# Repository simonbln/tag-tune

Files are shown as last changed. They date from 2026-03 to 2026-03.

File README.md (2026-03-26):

# tag-tune
An open-source, USB-powered audio player that brings physical objects to life.

## Table of Contents
1. [Components](#components)
2. [Wiring Diagram](#wiring-diagram)
3. [Firmware Details](#firmware-details)
4. [DFPlayer Mini & SD Card Setup](#dfplayer-mini--sd-card-setup)
5. [LED Status Indicators](#led-status-indicators)
6. [How to Use](#how-to-use)
7. [How to Build](#how-to-build)
    - [Breadboard Prototyping](#breadboard-prototyping)
    - [Firmware Setup](#firmware-setup)
    - [Important: USB Power Handling](#important-usb-power-handling)
    - [Build Prototype](#build-prototype)
8. [Support Me](#support-me)
9. [Third-Party Code and License](#third-party-code-and-license)

## Components
- RP2040 (Zero)
- DFPlayer Mini
- RC522 NFC reader
- USB Connector
- WS2812 (NeoPixel LED)
- 2 Speaker 3 Ohm 
- Micro SD Card
- Perfboard (5x7cm)
- Connectors / Cables
- Enclosure / Box

## Wiring Diagram
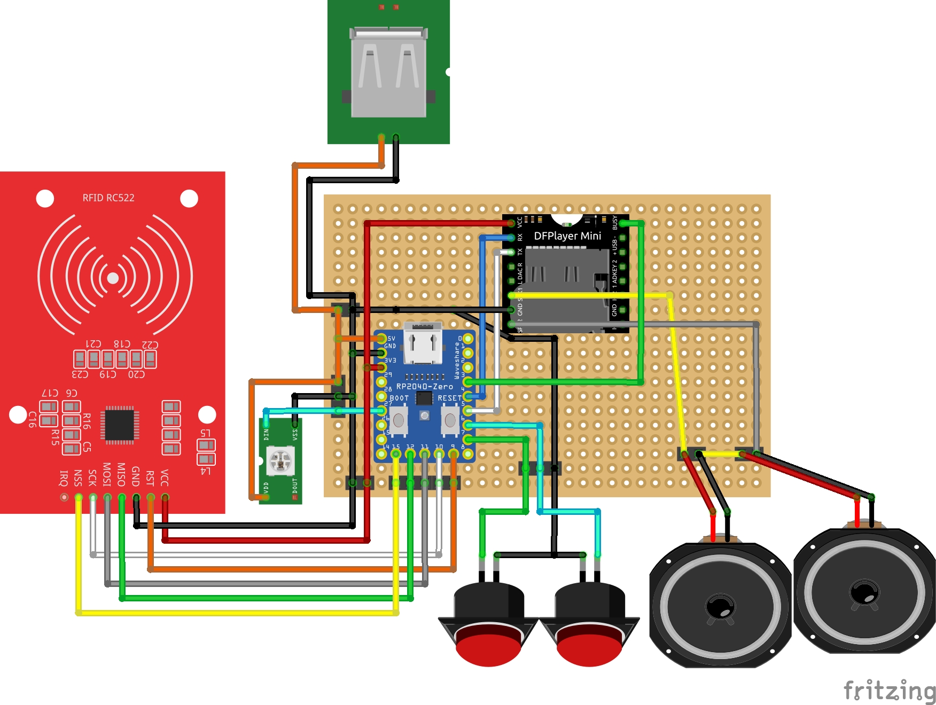
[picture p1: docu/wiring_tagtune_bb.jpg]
Wiring Diagram

Figure 1: Wiring diagram on the perfboard

## Firmware Details
The firmware is written in **MicroPython** and utilizes a modified version of the [penguintutor/dfplayermini-pico](https://github.com/penguintutor/dfplayermini-pico) library.

## DFPlayer Mini & SD Card Setup
The DFPlayer Mini requires the SD card to be formatted to **FAT16 or FAT32**.

### SD Card Structure
The module requires a specific file naming convention to function reliably:
- **Folder naming:** Use a folder named `01` in the root directory.
- **File naming:** Files should be prefixed with a three-digit number (e.g., `001.mp3`).

## LED Status Indicators
The WS2812 LED (internal on PIN 16 and (optional) extenal on PIN 28) provides visual feedback on the system's state:

- **White:** System is initializing.
- **Green:** Ready and waiting for NFC tag.
- **Blue:** Valid tag and playing
- **Cyan:**  Finished playing on tag
- **Red:**: Error: No SD card or invalid tag

## How to use

Copy music or audio stories onto an SD card. Write tags as plain text on NFC tags — you can use your smartphone for that. On the tag, write the numbers of the files you want to play, separated by commas, for example: 1,2,5 will play files 1, 2, and 5 in that order. You can also use ranges with a minus sign, like 12-20 (plays files 12 through 20), or just a single file like 33. 

Unfortunately, I can only read about 15 bytes from Ultralight NFC tags, so the list can't be too long — in that case you can use the range format instead, for example 102-139. 

If you remove the same tag and hold it up again later, playback resumes from where it stopped. If you hold up a different tag, playback starts from the beginning. You can also just take the tag away to pause playback. Use the buttons to skip to the next or previous track with a short press, and adjust the volume with a long press. 

You can glue the tags onto figures or other objects later. Have fun with your music box :)

## How to build

### Breadboard Prototyping
For initial testing, it is recommended to build the circuit on a breadboard first as shown in the wiring diagram.

### Firmware Setup
1. Install **Thonny** IDE on your computer.
2. Flash the **MicroPython firmware** to the RP2040.  
   > **Firmware download:** [MicroPython for RP2040](https://micropython.org/download/rp2-pico/)
3. Copy all files from the `firmware` folder to the RP2040.

### Important: USB Power Handling
- **Do not** connect an external USB power source to the additional USB port while the RP2040 is connected to your computer via USB.
- Once the RP2040 is disconnected from the computer, the external USB port can be used to power all components. But for testing purpose you can use the USB Port of the RP2040.
- The external USB port will later be integrated into the enclosure.

### Build prototype
Solder the components and wires onto the perfboard as shown in Figure 1. Once the assembly is complete, perform an initial functional test before mounting the board into the enclosure.

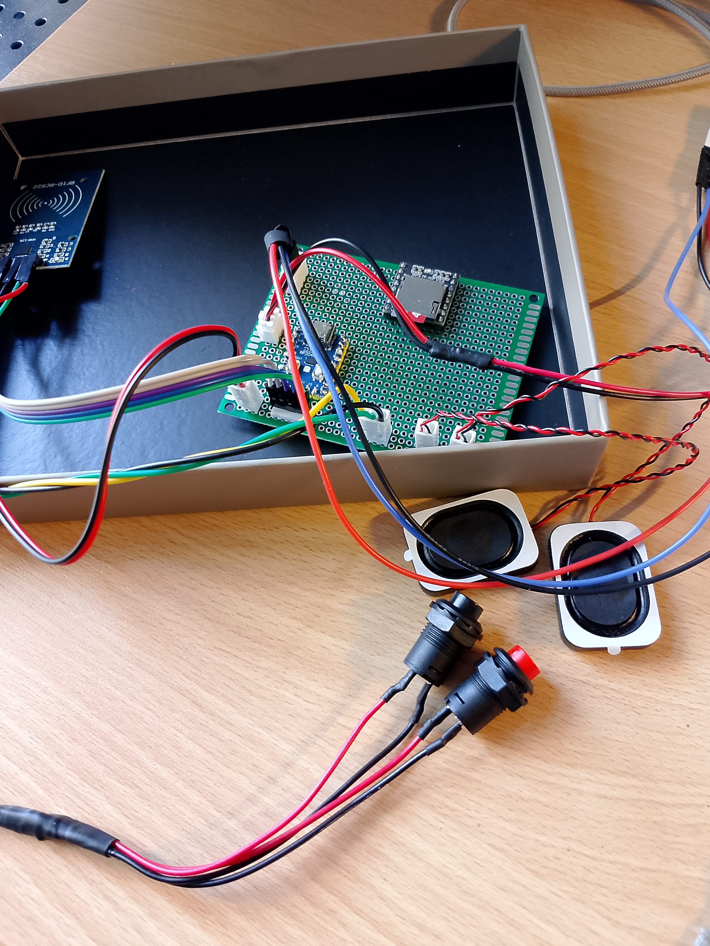
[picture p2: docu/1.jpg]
Soldering

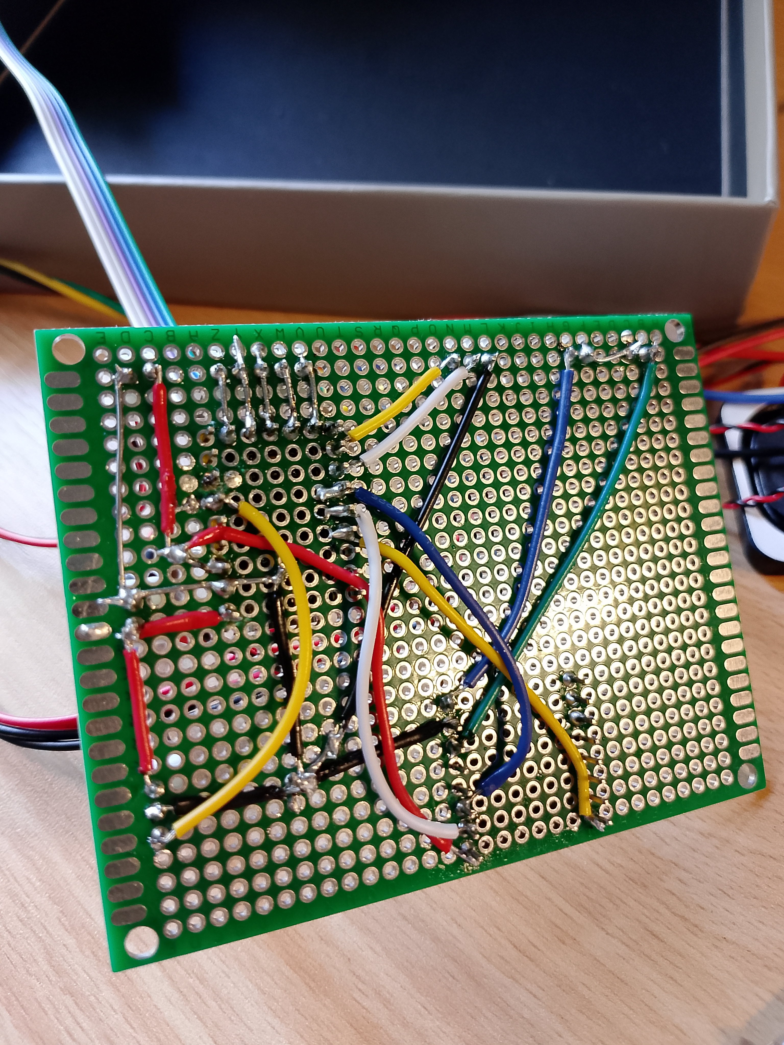
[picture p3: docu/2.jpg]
First Test


Drill the necessary holes for the cable glands and connectors, then insert them and secure with hot glue if necessary. The status LED was also routed through the lid for better visibility.

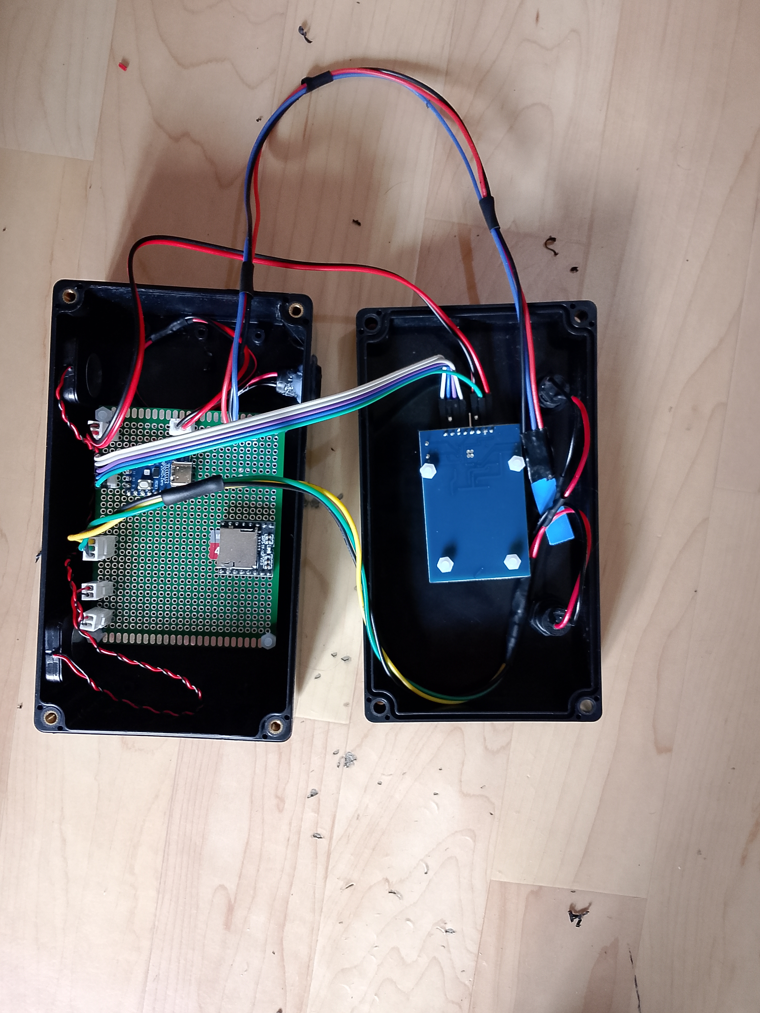
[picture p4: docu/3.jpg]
Progress

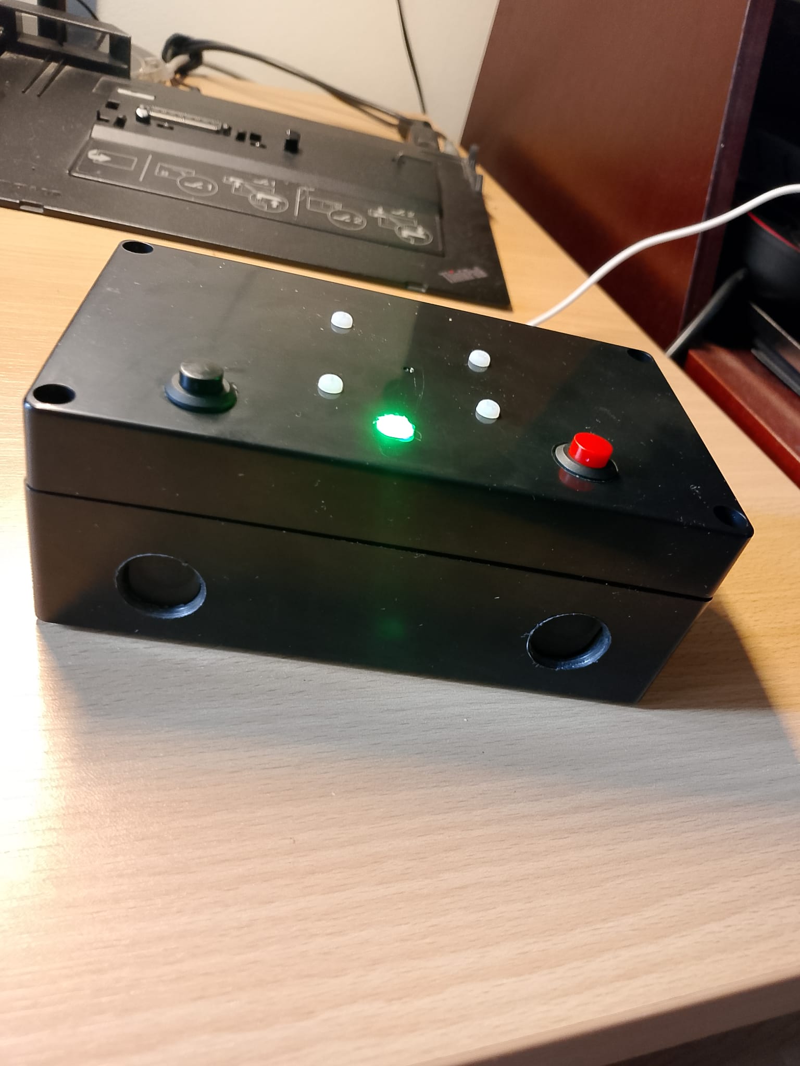
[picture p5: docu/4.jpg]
Finished


## Support me
If you find this project helpful and would like to support my work, I would be very grateful for a contribution via GitHub Sponsors or in Bitcoin (BTC) / Litecoin (LTC). Every bit of support helps me to keep creating and sharing new projects. Thank you!

### LTC:
ltc1qx2yf4cndqr2zf3vfd7l2ywm5hylvhm0a8jrxry

LTC QR Code

### BTC: 
bc1q5yga8eluxk7cn4pc7k36lwee06mwt5gtre8nrm

BTC QR Code

### Bitcoin Cash
bitcoincash:qp4gapsmpt75nh7clp64dhae2myhl9h8tg2f77w652

Bitcoin_Cash QR Code

## Third-Party Code and License

This project contains modified code from the [penguintutor/dfplayermini-pico](https://github.com/penguintutor/dfplayermini-pico) repository.

*   **Original Author:** [@PenguinTutor](https://www.penguintutor.com)
*   **Original Repository License:** **GNU General Public License v3.0** (GPL-3.0) – see full text in the original repository's `LICENSE` file.
*   **Modifications by:** ([@simonbln](https://github.com/simonbln))
*   **Date of modifications:** March 2026
*   **Nature of modifications:**
    1.  Updated `command.to_bytes(1)` to `command.to_bytes(1, 'big')` for compatibility with newer Python versions.
    2.  Fixed the return value parsing for the reset command to correctly handle the module's response.

This modified version is distributed under the same license terms (GPL-3.0). The complete license text is included in this repository as `LICENSE`.

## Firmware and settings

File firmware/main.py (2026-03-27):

from machine import Pin, UART, lightsleep, SPI
from mfrc522 import MFRC522
import utime
import time
import neopixel
import time
import random
from dfplayermini import DFPlayerMini

class NDEFDataManager:
    def __init__(self, reader, max_files):
        self.reader = reader
        self.max_files = max_files
        self.last_text = None
        self.values = []
        self.current_index = 0
        self.has_error = False
        self._is_resuming = False # Internal state for shall_resume()

    def check(self):
        """Reads the tag and manages the resume/state logic."""
        raw_text = self._read_from_tag()
        self._is_resuming = False # Reset resume state by default

        # Case 1: Tag was removed (raw_text is None)
        if raw_text is None:
            if self.last_text is not None:
                # Tag lost: clear active state but keep index/saved_text for potential resume
                self.last_text = None
                print("check: tag gone")
                return True # Status change: tag gone
            return False

        # Case 2: A tag is present
        # Check against hidden buffer to see if it's the SAME tag as before
        if hasattr(self, '_saved_text') and raw_text == self._saved_text:
            # Same tag content detected
            if self.last_text is None: # It was away, now it's back
                self.last_text = raw_text
                # If there are elements left, enable resume; otherwise restart from 0
                if self.current_index < len(self.values) and self.current_index >= 0:
                    self._is_resuming = True
                else:
                    self.current_index = 0
                    print(f"check: tag is back: {raw_text}")
                return True
            return False

        # Case 3: A completely new tag (or content changed)
        self.last_text = raw_text
        self._saved_text = raw_text # Persistent memory for resume check
        self.current_index = 0
        self._parse_values(raw_text)
        print(f"check: tag is new: {raw_text}")
        return True

    def shall_resume(self):
        """Returns True if the same tag was reapplied and has pending values."""
        return self._is_resuming

    def has_valid_tag(self):
        """Returns True if a tag is currently being detected."""
        return self.last_text is not None
    
    def get_first_value(self):
        if self.current_index < (len(self.values)) and self.current_index >= 0:
            val = self.values[self.current_index]
            print(f"get_first_value: {val}")
            if val <= self.max_files:
                print(f"get_first_value: {val}: OK")
                return val
        print("get_first_value: is not valid, get next")
        return self.get_next_value()

    def get_next_value(self):
        while self.current_index < (len(self.values)-1):
            self.current_index += 1
            val = self.values[self.current_index]
            print(f"get_next_val: {val}")
            if val <= self.max_files:
                print(f"get_next_val: {val}: OK")
                return val
        print(f"get_next_val: nothing found")
        self.current_index = len(self.values)
        return None
    
    def get_prev_value(self):
        while self.current_index > 0:
            self.current_index -= 1
            val = self.values[self.current_index]
            print(f"get_prev_value: {val}")
            if val <= self.max_files:
                print(f"get_prev_value: {val}: OK")
                return val
        print(f"get_prev_value: nothing found")
        self.current_index = -1
        return None
 

    def _parse_values(self, text):
        """Parses comma-separated string into an integer list.
           Supports ranges like '4-50' which expand to 4,5,6,...,50.
        """
        self.values = []
        self.current_index = 0
        self.has_error = False
        try:
            parts = text.strip().split(',')
            for p in parts:
                cleaned = p.strip()
                if not cleaned:
                    continue
                try:
                    # Einzelne ganze Zahl
                    self.values.append(int(cleaned))
                except ValueError:
                    # Keine einzelne Zahl → möglicher Bereich
                    if '-' in cleaned:
                        range_parts = cleaned.split('-')
                        if len(range_parts) == 2:
                            start_str, end_str = range_parts
                            start = int(start_str.strip())
                            end = int(end_str.strip())
                            if start <= end:
                                self.values.extend(range(start, end+1))
                            else:
                                raise ValueError("Invalid range: start > end")
                        else:
                            raise ValueError("Invalid range format: more than one dash")
                    else:
                        raise ValueError("Invalid integer or range")
        except ValueError:
            self.has_error = True
            self.values = []

    def _read_from_tag(self):
        """Hybrid read logic for Ultralight and Classic tags."""
        all_raw_data = bytearray()
        
        self.reader.init()
        (stat, _) = self.reader.request(self.reader.REQIDL)
        if stat != self.reader.OK: return None
        (stat, uid) = self.reader.SelectTagSN()
        if stat != self.reader.OK: return None

        # Try Ultralight first (Pages 4-15)
        for page in range(4, 16):
            s, d = self.reader.read(page)
            if s == self.reader.OK and d:
                all_raw_data.extend(bytes(d))
            else: break

        # Try Classic if Ultralight yielded no NDEF data
        if len(all_raw_data) < 7:
            self.reader.stop_crypto1() # Clean up state
            self.reader.init()
            self.reader.request(self.reader.REQIDL)
            self.reader.SelectTagSN()
            nextKey = [0xD3, 0xF7, 0xD3, 0xF7, 0xD3, 0xF7]
            for b in [0, 1, 2]:
                res = self.reader.readSectorBlock(uid, 1, b, nextKey, None)
                s, d = res if isinstance(res, tuple) else (self.reader.OK, res)
                if s == self.reader.OK and d:
                    all_raw_data.extend(bytes(d))
            self.reader.stop_crypto1()

        # NDEF Text Record Parser
        i = 0
        while i < len(all_raw_data) - 4:
            if all_raw_data[i] == 0x03: # NDEF Start
                msg_len = all_raw_data[i+1]
                try:
                    for j in range(i + 2, i + 8):
                        if all_raw_data[j] == 0x54: # 'T' identifier
                            p_len = all_raw_data[j-1]
                            l_len = all_raw_data[j+1] & 0x3F
                            start = j + 2 + l_len
                            end = j + 1 + p_len
                            return all_raw_data[start:end].decode('utf-8')
                except: pass
                i += 2 + msg_len
            elif all_raw_data[i] == 0xFE: break # NDEF End
            else: i += 1
        return None



# --- Configuration ---
BTN_NEXT_PIN = 6
BTN_PREV_PIN = 7
DEBOUNCE_MS = 50 
LONG_PRESS_MS = 1000
VOL_STEP_MS = 500

BUSY_PIN = 3

LED1_PIN = 16
LED2_PIN = 27

# --- Global States ---
# We store (timestamp, is_pressed)
btn_states = {
    BTN_NEXT_PIN: {"start_time": 0, "active": False, "long_done": False},
    BTN_PREV_PIN: {"start_time": 0, "active": False, "long_done": False}
}


# --- Shared ISR for Buttons ---
def btn_isr(pin):
    pin_num = 6 if "6" in str(pin) else 7 # Simple way to get ID
    if pin.value() == 0: # Pressed (Falling)
        if not btn_states[pin_num]["active"]:
            btn_states[pin_num]["start_time"] = utime.ticks_ms()
            btn_states[pin_num]["active"] = True
            btn_states[pin_num]["long_done"] = False
    else: # Released (Rising)
        btn_states[pin_num]["active"] = False
        
# Setup Pins
btn_next = Pin(BTN_NEXT_PIN, Pin.IN, Pin.PULL_UP)
btn_prev = Pin(BTN_PREV_PIN, Pin.IN, Pin.PULL_UP)
btn_next.irq(trigger=Pin.IRQ_FALLING | Pin.IRQ_RISING, handler=btn_isr)
btn_prev.irq(trigger=Pin.IRQ_FALLING | Pin.IRQ_RISING, handler=btn_isr)

pixel = neopixel.NeoPixel(Pin(LED1_PIN), 1)
pixel2 = neopixel.NeoPixel(Pin(LED2_PIN), 1)

busy_pin = Pin(BUSY_PIN, Pin.IN)

class Colors:
    RED     = (20, 0, 0)
    GREEN   = (0, 20, 0)
    BLUE    = (0, 0, 20)
    YELLOW  = (50, 50, 0)
    CYAN    = (0, 50, 50)
    MAGENTA = (20, 0, 20)
    WHITE   = (20, 20, 20)
    OFF     = (0, 0, 0)
    
last_color =  Colors.OFF

def set_pixel_color(color_rgb):
    global last_color
    if last_color != color_rgb:
        #pixel[0] = color_rgb
        pixel2[0]= color_rgb
        #pixel.write()
        pixel2.write()
        last_color = color_rgb
        
def wait_until_playing(timeout_ms=500):
    start = utime.ticks_ms()
    while utime.ticks_diff(utime.ticks_ms(), start) < timeout_ms:
        if busy_pin.value() == 0:
            utime.sleep_ms(10)
    return False
        


def main():
    print("start")
    
    time.sleep(1)
    set_pixel_color(Colors.WHITE)
    time.sleep(1) # needs time when everything is powered together
    player = DFPlayerMini(1,4,5)

    
    while True:
        print ("Reset")
        if player.reset() == True:
            print ("Reset: OK")
            break
        time.sleep(1)

    time.sleep(1) # needs time after a reset
    player.select_source('sdcard')

    print ("Read Num files")
    count_songs = player.query_num_files()
    print (f"Num files {count_songs}")

    if count_songs == 0:
        while True:
            set_pixel_color(Colors.RED)
            time.sleep(10)

    player.set_volume(20)
    print ("Read volume")
    current_vol = player.get_volume()
    print (f"Volume {current_vol}")
    
    reader = MFRC522(spi_id=1, sck=10, mosi=11, miso=12, cs=13, rst=9)
    manager = NDEFDataManager(reader, count_songs)

    led_yellow_until = 0
    last_vol_tick = 0
    color_led = Colors.GREEN
    loop_count = 0

    while True:
        now = utime.ticks_ms()
        
        # Process both buttons
        for pin_id in [BTN_NEXT_PIN, BTN_PREV_PIN]:
            state = btn_states[pin_id]
            
            if state["active"]:
                duration = utime.ticks_diff(now, state["start_time"])
                
                # Long Press Logic (Volume)
                if duration > LONG_PRESS_MS:
                    set_pixel_color(Colors.YELLOW)
                    led_yellow_until = now + 200
                    if utime.ticks_diff(now, last_vol_tick) > VOL_STEP_MS:
                        
                        if pin_id == BTN_NEXT_PIN:
                            current_vol = min(current_vol + 1, 30)
                            print(f"Volume UP: {current_vol}")
                        else:
                            current_vol = max(current_vol - 1, 0)            
                            print("Volume DOWN")
                        
                        player.set_volume(current_vol)
                        last_vol_tick = now
                        state["long_done"] = True

        #Short Press Logic (Next/Prev Song)
        # Detect release after a short press
        for pin_id in [BTN_NEXT_PIN, BTN_PREV_PIN]:
            state = btn_states[pin_id]
            if not state["active"] and state["start_time"] > 0:
                duration = utime.ticks_diff(now, state["start_time"])
                if DEBOUNCE_MS < duration < LONG_PRESS_MS:
                    set_pixel_color(Colors.YELLOW)
                    led_yellow_until = utime.ticks_ms() + 200
                    if manager.has_valid_tag():
                        val = None
                        if pin_id == BTN_NEXT_PIN:
                            val = manager.get_next_value()
                            print(f"Action: NEXT SONG: {val}")
                        else:
                            val = manager.get_prev_value()
                            
                            print(f"Action: PREV SONG: {val}")                        
                        if val:
                            color_led = Colors.BLUE
                            player.play(val)
                            wait_until_playing()
                        else:
                            #nothing to play
                            player.stop()
                            color_led = Colors.CYAN
                
                state["start_time"] = 0 
                state["active"] = False

        #LED Control
        if utime.ticks_ms() < led_yellow_until:
            set_pixel_color(Colors.YELLOW)
        else:
            # Fall back to normal tag-based color
            set_pixel_color(color_led)
            
        #check for nfc tag
        if (loop_count % 10) == 0:
            if manager.check():
                if manager.has_valid_tag():
                    print("new tag")
                    if manager.has_error:
                        color_led = Colors.RED
                    else:
                        color_led = Colors.BLUE
                        if manager.shall_resume():
                            player.start()
                            wait_until_playing()
                        else:
                            val = manager.get_first_value()
                            if val:
                                player.play(val)
                                wait_until_playing()
                            else:
                                #nothing to play
                                color_led = Colors.CYAN
                else:
                    player.pause()
                    color_led = Colors.GREEN
                    print("no tag")
                    
            if color_led == Colors.BLUE and busy_pin.value() != 0:
                #supposed to playing but not anymore, go to next
                val = manager.get_next_value()
                print(f"song finished, next one: {val}")
                if val:
                    player.play(val)
                    wait_until_playing()
                else:
                    #nothing to play
                    color_led = Colors.CYAN
      
        loop_count = (loop_count + 1) % 100
        utime.sleep_ms(50)
    

if __name__ == "__main__":
    try:
        main()
    except Exception as e:
        while True:
            set_pixel_color(Colors.RED)
            time.sleep(0.5)
            set_pixel_color(Colors.OFF)
            time.sleep(0.5)

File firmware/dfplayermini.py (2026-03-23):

# A library to control the DFPlayer MP3 player
# Only partial implementation
# For more details of protocol see https://www.dfrobot.com/
# Created by Stewart Watkiss @PenguinTutor
# https://www.penguintutor.com 



# Original code by Stewart Watkiss @PenguinTutor
# https://www.penguintutor.com
# Source: https://github.com/penguintutor/dfplayermini-pico
# License: GNU General Public License v3.0 (GPL-3.0)
#
# Modified by simonbln - March 2026
# Changes:
# - command.to_bytes(1) -> command.to_bytes(1, 'big') for compatibility with newer Python versions
# - Fixed reset command return value parsing


from machine import UART, Pin
import time

class DFPlayerMini ():
    
    # how long to pause between read and write / subsequent reads
    sleep_time = 0.2
    debug = False
    
    sources = {
        'usb': 1,
        'sdcard': 2,
        'sd': 2,         # Allow sd as well as sd card
        'aux': 3,
        'sleep': 4,
        'flash': 5
        }
    
    def __init__ (self, uart_no, tx, rx):
        self.uart = UART(uart_no, baudrate=9600, tx=Pin(tx), rx=Pin(rx))
        self.uart.init(9600, bits=8, parity=None, stop=1)
        # Set to source when configured
        self.source = None
        # Keep track of if paused
        # Eg. allows resuming paused track when play is pressed
        self.paused = False
        
       
    # Simple check that looks for a standard 0x40 return code
    def check_return (self, byte_string):
        if byte_string[3] == 0x40:
            print ("Error receiving data")
            return False
        return True 
        
        
    # Send a byte string (bytes should alread be fully encoded)
    # then return the response
    def send_bytes (self, byte_string):
        sent_count = self.uart.write(byte_string)
        time.sleep(self.sleep_time)
        return self.read_reply()
        
    # Get a response - part of send_bytes, but also called seperately
    # where multiple replies are expected
    def read_reply (self):
        read_value = self.uart.read(10)
        if self.debug:
            if read_value == None:
                print ("None received")
                return None
            string_received = "".join([f"\\x{byte:02x}" for byte in read_value])
            print (f"Received {string_received}")
        return read_value
    
    
    def calc_checksum(self, data):
        # Data string
        sum = 0
        for byte in data:
            sum += byte
        #Convert to twos complement
        twos = (0xFFFF + 1 - sum)
        return twos
    
    def send_command (self, command, value=0, feedback=1):
        # Start = 7E
        # Version = FF
        # Len = 06
        # cmd
        # feedback = 1 or 0 (Whether response required) typically 1 for yes
        # para 1 (high data byte)
        # para 2 (low data byte)
        # checksum (from Version to para2) - 2 bytes
        # End = EF
        
        # Data without start, end or checksum
        data = b'\xFF\x06' + command.to_bytes(1, 'big') + feedback.to_bytes(1, 'big') + value.to_bytes(2, 'big')
        # Add checksum to data
        checksum = self.calc_checksum(data)
        data += checksum.to_bytes(2, 'big')
        # Add start and end bytes
        data_string = b'\x7E' + data + b'\xEF'
        string_sent = "".join([f"\\x{byte:02x}" for byte in data_string])
        if self.debug:
            print (f"Sending: {string_sent}")
        
        return self.send_bytes (data_string)
    
    def reset(self):
        self.paused = False
        #'reset' : b'\x7E\xFF\x06\x0C\x01\x00\x00\xFE\xEE\xEF'
        return_value = self.send_command(0x0C)
        #print(return_value)
        #print(len(return_value))
        #print (f"Return 1: {return_value}")
        # First return will be x41 with 0,0,0
        # Check for no return value or length of value is not correct
        if return_value == None or len(return_value) != 10:
            # If so just return without checking for a value
            return False
        # Reset wait 2 x sleep as sometimes needs to stabilise first
        time.sleep(self.sleep_time)
        time.sleep(self.sleep_time)
        # Next value should be x3f with 0,0,<response>
        return_value = self.read_reply()
        #print(return_value)
        #print(len(return_value))
        if len(return_value) == 1 and return_value[0] ==0x00:
            return True
        if return_value == None:
            # If so just return without checking for a value
            return False
        if len(return_value) != 10:
            return False
        #print (f"Return 2: {return_value}")
        # Now check for a valid return value - lower data byte = [6]
        # 0 = Timeout
        #string_recv = "".join([f"\\x{byte:02x}" for byte in return_value])
        if return_value[3] != 0x3f:
            # Expecting 3f - if not then just return false
            return False
        # 2 = Cardinserted, 4 = CardOnline, 7 = USBInserted, 9 = USBOnline, 10 = CardUSBOnline
        if return_value[6] in (0x02, 0x04, 0x07, 0x09, 0x10):
            return True
        # Any other value return False
        return False


    # Get number of files on card / disk / flash
    # If source is default or None then uses current source
    def query_num_files(self, source=None):
        query_code = None
        # If no source set use current, otherwise return false
        if source == None:
            if self.source == None:
                return False
            source = self.source

        # Now source is set from parameter or using defult
        # Different from datasheet which says x47 - TF card, x48 = U-disk
        if source in ('sdcard', 'sd'):
            query_code = 0x48
        elif source == 'usb':
            query_code = 0x47
        elif source == 'flash':
            query_code = 0x49
            
        
        return_value = self.send_command(query_code)
        print (f"query_num_files {return_value}")
        # Check for no return value or length of value is not correct
        if return_value == None or len(return_value) != 10:
            # If so just return without checking for a value
            return False
        time.sleep(self.sleep_time)
        # Now check for a valid return value - lower data byte = [6]
        return_value = self.read_reply()
        # Now check for a valid return value - lower data byte = [6]
        # 0 = Timeout
        #string_recv = "".join([f"\\x{byte:02x}" for byte in return_value])
        if return_value[3] != query_code:
            # Expecting 3f - if not then just return false
            return False

        # Return value of lower byte + upper byte x (FF+1)
        eval_value = (return_value[5] * 256) + return_value[6]
        print (f"Eval {eval_value}")
        return eval_value
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

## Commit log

2026-03-23 first step: not in enclosure yet, but everything works so far
    [wiring_tagtune.fzz, wiring_tagtune_mono.fzz]
2026-03-23 Update wiring diagram image in README
2026-03-23 fix wiring diagram
    [wiring_tagtune_mono.fzz]
2026-03-27 Increase default volume, decrease brightness of status LED, improve startup
